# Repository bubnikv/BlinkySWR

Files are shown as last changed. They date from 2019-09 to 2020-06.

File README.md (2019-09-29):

# BlinkySWR

Tiny, cheap, simple, accurate, self powered resistive SWR and power meter for SOTA and back packers

The SWR and power meter is based on a resistive bridge. The forward and reflected power is sampled by an ATTiny13A micro controller. The micro controller is powered by rectifying a tiny fraction of the input power, and the measured SWR and power is displayed by smoothly interpolating 6 high efficiency LED diodes.

Firmware for the ATTiny13A is found [here](firmware), while the simulation and design data is found [here](design).

The following picture shows the initial prototype of BlinkySWR, indicating SWR slightly above 1:1.
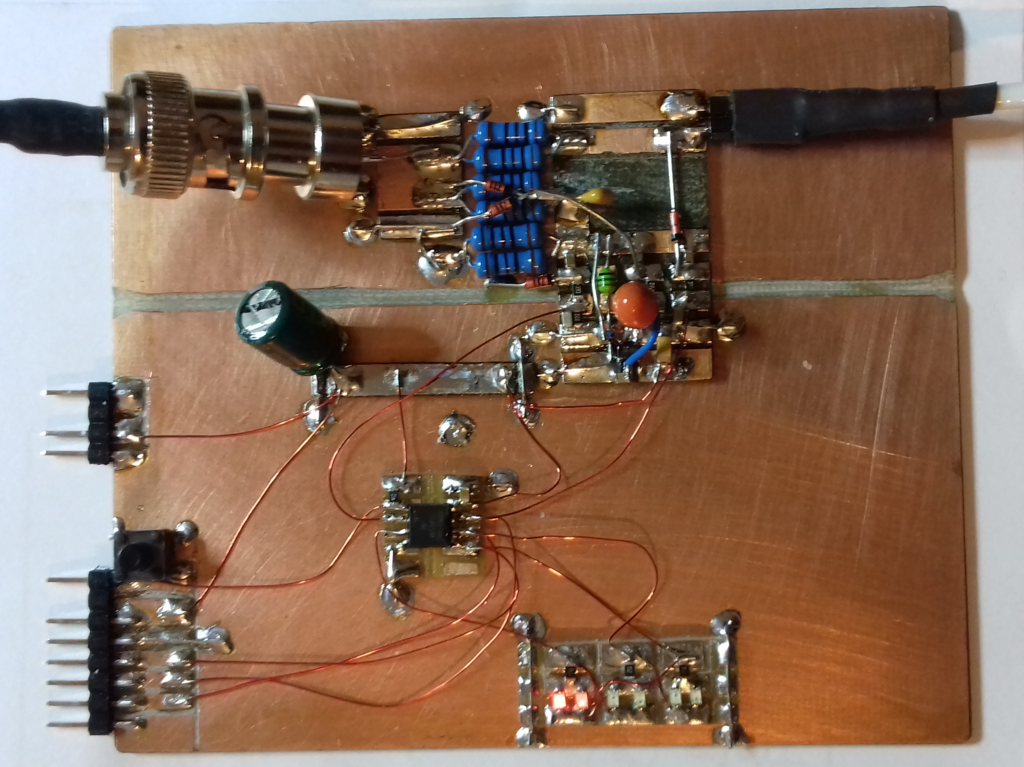
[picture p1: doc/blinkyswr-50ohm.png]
BlinkySWR prototype


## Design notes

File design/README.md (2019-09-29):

# Simulation and design

The BlinkySWR DC power recovery and SWR sampling circuits were simulated using the excellent free, unfortunately not open source [LTSpice](https://www.analog.com/en/design-center/design-tools-and-calculators/ltspice-simulator.html) tool by Linear Technologies. Installers for Windows and OSX are provided, and Linear Technologies makes sure that the Windows build runs under Wine on Linux.

The data produced by LTSpice was processed using the [Octave](https://www.gnu.org/software/octave/) software package, which is a free and open source alternative to [Matlab](https://www.mathworks.com/products/matlab.html) by [MathWorks](https://www.mathworks.com).

### Sampling circuit correction

The forward and reverse power is sampled by a hot carrier Shottky diode 1N5711, and the voltage drop at the sampling diode follows roughly the [Shockley diode equation](https://en.wikipedia.org/wiki/Shockley_diode_equation). We take an approach of modelling the sampling circuit in LTSpice using the SPICE model of the 1N5711 provided by [Diodes Incorporated](https://www.diodes.com/design/tools/spice-models/), providing a richer description of the diode behaviour than the [Shockley diode equation](https://en.wikipedia.org/wiki/Shockley_diode_equation) parameters. The SPICE model of the 1N5711 diode represents typical behavior of the diode at a room temperature, therefore the power and SWR reading by the BlinkySWR will not be quite accurate at freezing temperatures or under the desert sky. Temperature calibration is possible by putting another diode into a feedback loop of an op amp as in the [Accuprobe](http://www.kk5na.com/kk5na_files/AccupManual.htm) by the superb QRP designer Joe Everhart N2CX (SK), or by measuring a voltage drop at a reference diode by the microcontroller, but the ATTiny13A has no free input available and we did not want to complicate the design with an op amp.

[ltspice/blinky-diode-curve-parametric.asc](ltspice/blinky-diode-curve-parametric.asc) is an LTSpice model of input power sampling circuit including the ATTiny13A A/D sampling circuit, parametrized with SPICE STEP command to produce simulations for with the SWR bridge open (SWR infinity, transceiver sees SWR 1:2 and it produces maximum peak voltage). The .raw file produced by LTSpice contains transient analysis curves for input peak voltages from 0 to 50V peak. The .raw file is processed by [matlab/blinky-diode-curve.m](matlab/blinky-diode-curve.m) script to produce [matlab/blinky-diode-curve.mat](matlab/blinky-diode-curve.mat) sampling diode correction curve.

The following image shows the simulated diode correction curve. The voltage at the X axis represents the A/D reading, while the Y axis represents the diode voltage drop, which needs to be added to the A/D reading to get the sampled voltage. Blue curve represents the correction curve at room temperature for a typical 1N5711 diode, while the red line represents a linear interpolation of the curve. It is clear, that the diode voltage drop is far from 0.3V for the hot carrier 1N5711 diode, usually much higher (0.5V to 0.9V).

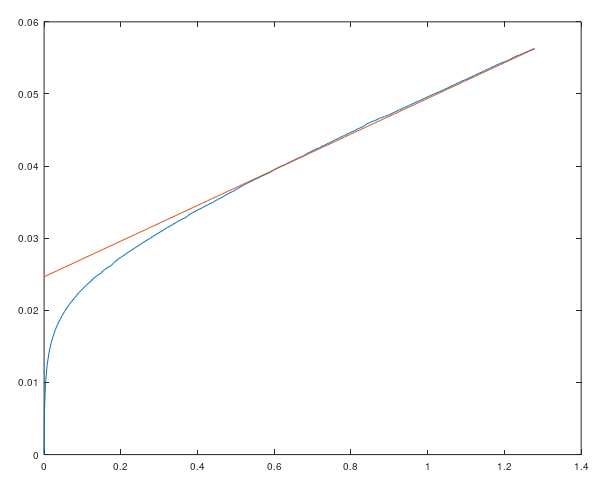
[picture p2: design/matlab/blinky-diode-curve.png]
1N5711 diode correction curve


### Other models

[ltspice/blinky-power-supply.asc](ltspice/blinky-power-supply.asc) - model of the DC power recovery, to be used for assessing currents through the diodes, loading of the transceiver and harmonics created by the loading, driven with 7MHz / 1W source.

[ltspice/blinky-diode-curve.asc](ltspice/blinky-diode-curve.asc) - model of input power sampling circuit including the ATTiny13A A/D sampling circuit, with balanced SWR bridge, driven with 7MHz / 1W source.

[ltspice/blinky-diode-curve-open.asc](ltspice/blinky-diode-curve-open.asc) - model of input power sampling circuit including the ATTiny13A A/D sampling circuit, with the SWR bridge open (SWR infinity, transceiver sees SWR 1:2 and it produces maximum peak voltage), driven with 7MHz / 1W source.

### 3rd party models and scripts

[ltspice/spicemodels_schottky_diodes.txt](ltspice/spicemodels_schottky_diodes.txt) - SPICE model of 1N5711 diode, from [ltwiki.org](http://ltwiki.org/files/LTspiceIV/Vendor%20List/Diodes%20Incorporated/Spice/spicemodels_schottky_diodes.txt)

[matlab/LTspice2Matlab.m](matlab/LTspice2Matlab.m) - 
Import of ltspice .raw files (simulation results), by [Paul Wagner](https://www.mathworks.com/matlabcentral/fileexchange/23394-fast-import-of-compressed-binary-raw-files-created-with-ltspice-circuit-simulator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), extended for Octave compatibility by [Thorben Casper](https://github.com/tc88/ANTHEM/blob/master/src/LTspice2Matlab.m)

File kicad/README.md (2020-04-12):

# BlinkySWR PCB board

KiCad PCB layout
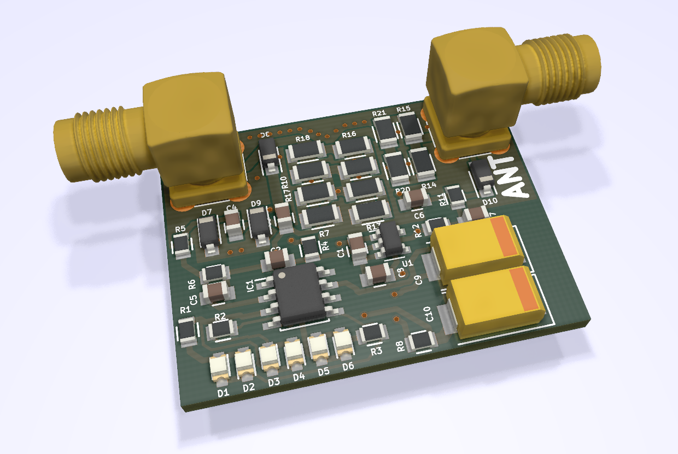
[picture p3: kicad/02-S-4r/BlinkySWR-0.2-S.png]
PCB


* [Schematics rev0.2](02-S-4r/BlinkySWR-0.2-S.pdf)
* [Interactive bom](http://htmlpreview.github.io/?https://github.com/bubnikv/BlinkySWR/blob/master/kicad/02-S-4r/ibom.html)
* [STEP 3D model](02-S-4r/BlinkySWR-0.2-S.step)

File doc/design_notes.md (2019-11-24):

# BlinkySWR design notes

The BlinkySWR is an ATtiny SWR and power meter, basically a smarter
replacement of the famous Tayloe SWR bridge. It will be a 1W to 5W (maybe a
bit higher, up to 10W) QRP resistive bridge with 6 LEDs analog-like
baragraph, with the intensity being interpolated between two successive
LEDs enhancing the baragraph resolution to at least 4x6 levels (I can
easily recognize 1 LED illuminated from 2 LEDs equally illuminated and 1
LED illuminated significantly stronger than the other). I have the
baragraph electronics and code prototyped, it works quite nicely.

The electronics (ATtiny13A driving the 6 LEDs) will be powered from a 3V
low drop low low quiescent current 16V max input linear regulator, and the
linear regulator will be powered with a 1:2 or 1:3 transformer from the
radio RF power, rectified by a single 1n5711 shottky diode (the diodes will
be used in the bridge anyway, so to reduce the BOM complexity). Look ma, no
batteries.

There will be a larger capacitor at the input side of the regulator, so the
microprocessor will have couple of seconds to perform additional tasks
after key up, that is to show the input power with quite a high accuracy.
So there will be no button: SWR will be shown during key down, and power
will be shown after a second or so after key up.

I feel quite confident with digital design and programming, but I am not
quite sure about the RF
side. Namely, what transformer should I use to feed the linear regulator?

These are my back of the envelope calculations:

On the transceiver output, when loaded with an open resistive bridge (all
three resistors 50 Ohm), the SWR is 2:1 and the voltage at the transceiver
output is 1.3333 * of Vpeak (assuming 50 Ohm output impedance of the
transceiver). Likely the maximum voltage will be lower as the output
impedance of the transceiver PA is not resistive. These are the maxima:
10W -> 42.16V Vpeak at SWR 2:1
7W -> 35.28V Vpeak at SWR 2:1
6W -> 32.65V Vpeak at SWR 2:1
5W -> 29.81V Vpeak at SWR 2:1

The minimum Vpeak at 1W transceiver output with the resistive bridge
shorted (again producing SWR 2:1 at the transceiver) will be minimum 8V
assuming the transceiver PA output is resistive. If not, the output voltage
will be closer to 10V peak.

Now the digital circuit requires a minimum 3.1V at 1.5mA DC before the
linear stabilizer, and the power will be rectified with a single diode, but
the micro will likely work happily down to 2V even if the linear regulator
just passes the voltage unregulated, as the micro may use its internal 1.1V
voltage reference for measurements. Operating the micro unregulated sounds
unusual, but it may be a viable option if tested, especially if the input
voltage will be stable enough due to the large capacitor before the
regulator.

Now my question is:
1) Should I use a 1:2 or 1:3 transformer? Using the 1:2 transformer may
require additional zener diode and likely a resistor before the linear
stabilizer if the input voltage could exceed 16V peak.
2) What will be the tiniest / cheapest ferrite and how many widings will be
optimal? I suppose this decision will be strongly dependent on the bands
supported. My personal goal is a 40m-20m EFHW tuner.

And also:

Will there be an interest for a kit?
Through hole or SMD? It may be a nice "introduction to SMD" kit as the
number of parts will be pretty low.
What bands?
What power range?
Should it contain an EFHW tuner? My personal preference would be a "NJQRP
Rainbow Tuner" like setup covering 40m-20m with a T50-6 transformer, mica
compression capacitor trimmer, jumpers to select the primary winding with
another jumper to add a capacitance for 40m coverage.

Thanks and 73,
Vojtech OK1IAK (former AB2ZA)

By kb1gmx

I pondered the idea an using a QRP radio or even a 20W radio where 
some larger chunk of power out goes to SWR/power meter tp power it
seems wrong.   Even if the suggested electronics uses a watt on a 5W 
radio that's a lot of power not going to the antenna.

Also Tayloe bridge SWR meters are a source of some 6-10db of 
insertion loss.  This is good while tuning the antenna as it 
protects the transmitter from a bad swr but unacceptable 
for inline use.   So the SWR detector (directional coupler) for inline
use should be of the Tandem match type or similar and even 
that sampler eats a little transmitter power.  The only point 
for it is now reflected power so a simple display works fine.
For power a meter will be far higher resolution.

Why not just use power from the radios  9-15V battery or an internal one? 
 Saves a lot of extra electronics and doesn't hurt the power out of the TX.
For intermittent use the battery would be small.

As to the EFHW antenna matching unit make it outboard in case 
you use a different antenna.  For 40-202m a T50-2 or T68-2 should 
do the job there are lots of schemes on the net for doing this.

Allison

Vojtech Bubnik
Even if the suggested electronics uses a watt on a 5W radio that's a lot of power not going to the antenna.
The suggested SWR meter shall draw roughly 1.5mA using a 1:2 or 1:3 transformer from the transceiver. Using a 1:2 transformer, with the assumption that only the positive polarity peak will be rectified, to source a 1.5mA voltage regulator, the circuit will draw 3mA from the source at the positive voltage peaks. Transformed by the 1:2 transformer, the current requirement will be halved, that is 1.5mA. 

At 5W the maximum peak voltage at the transmitter terminals when loaded with an open resistive bridge will be 29.81V. That corresponds to a 45mW power loss mostly in the linear regulator, that is roughly 1% of the input power.
At 10W it will be 63mW.
At 1W the power drawn to source the SWR meter electronics will be 10V * 1.5mA = 15mW, that is still 1.5% of the input power, that corresponds to -18dB power lost.

The SWR bridge current requirements may likely be even a bit lower, the 1.5mA is quite a conservative estimate using lower CPU speed and highest efficiency LED diodes.

I would be thankful if you correct my thoughs if I am wrong. I am more a software engineer than an electronics engineer.

Vojtech

kb1gmx

If your running a micro 1.5ma seems very low and LEDs you can see in 
daylight want a few ma to themselves.

Also don't forget the transformer and rectifier is a load ont he transmitter and 
that is in parallel with the antenna or dummy load which contributes to
SWR .  That whole DC recovery has an impedance and what is that?
How will the transmitter behave with that addded (loss in power 
and stability with a mismatched load).

There is no something for nothing in RF if your using power from the 
transmitter you also contributing load and possible reactance to the 
transmitters total load.  Also the transformer, rectifier and power 
converter do not deliver efficiency as components have loss.

That and the spec for the MPU used may hit low power but 
soon as the IO and A/D does something that goes up.

If the power needed is so low a few coin cells would power 
it for a very long time.  A CR3020  cell is about 225mah. 
That would save messing with RF and dealing with 
inefficiencies of power conversion.  You already have a 
battery to run the transmitter why suffer the cost in 
efficiency and losses (transfomer loss, rectifier loss, 
regulator loss) to convert DC to RF and then back to 
DC.  Keep in mind that a CW rig running class E might 
be 90% efficient but if it s class C its only 70% and 
it can easily be lower. If SSB those linear amps are maybe 
55% at full power and at less than half power 25% would 
be good.  So converting precious battery to RF then back 
to DC is at best inefficient.

You are correct save for your also incomplete in your loss projections.
Transformers are not 100% efficient, same for diodes (.2V at 1.5ma is 
0.3 mw of loss per diode).  Since the diodes are switches they generate 
harmonic waveforms that will be contributed to the output of the 
transmitter.  That's harder to predict as it varies with power in and 
load power needs.  In any case it needs to sty below the requirent
but the telecommunications rehulatory (FCC, PTT, other) 
agencies as well as good engineering practice.

In the end you get pecked to death a little at a time by ducks.

I do hardware, software, as well as RF for the last 50 years.

Allison
-- 

Vojtech Bubnik
There are two reasons to try it: First, it is challenge therefore fun. Second, it shall be an external box and it is great to not to worry about flat batteries.

1 mA flowing through a clear high intensity red LED makes my eyes hurt indoors.

Since the diodes are switches they generate 
harmonic waveforms that will be contributed to the output of the 
transmitter.

I will draw the current before the resistive bridge, therefore the harmonics will be attenuated. And the harmonics will be generated during the tune procedure only. I suppose that at 1.5% power consumed by the rectifier these harmonics will be quite weak.

I think it is time to test it. If I fail, at least I will learn something. Going shopping for the linear regulators.

Vojtech

I have a prototype working, see the attached photos showing the infinite SWR with open antenna terminals by lighting up the last LED, and showing a SWR roughly 1:1.1 with a 50 Ohm load. The bridge is powered with around 1.5W input power at 40m.

The six orange LEDs are interpolated by PWM, showing smooth transitions between levels. The SWR scale is following:
1st LED - 1:1
2nd LED - 1:1.5
3rd LED - 1:2
4th LED - 1:3
5th LED - 1:5
6th LED - 1:8 and higher

therefore the 1st LED being illuminated significantly more than the 2nd LED indicates SWR somwhere between 1:1 and 1:125.

On key up, the SWR meter is powered from a large 1000uF capacitor for around 1 second to blink the power detected on the 6 LED scale. I think that is all the functionality I can manage to squeeze into the 1kB of FLASH of this tiny $1 micro.

The device works somehow, but it is far from optimal. The micro is powered by a full wave rectifier with an artificial ground in the middle of the resistive bridge. As long as the current drawn is low, such arrangement should not cause significant read out errors or harmonics generated. I plan to do simulations of harmonic content in ltspice. The SWR bridge electronics is grounded to the virtual ground with a low impedance wire, therefore it shall be physically as tiny as possible to produce as little as possible capacitance against the other poles of the bridge, and this capacitance shall be balanced. The other three connections from the electronics to the SWR bridge are high impedance (1kOhm for power, 39kOhm for the forward and reflected power read outs).
 I do not consider myself an expert in RF electronics, though I have a feeling that such a setup will be less than optimal above 20m due to the low impedance path between the electronics ground and the virtual ground at the bridge, but with today's tiny SMD circuitry the capacity may be lower than expected.

There is a lot of work to be done on fine tuning the firmware and possibly the circuit. The firmware should utilize power saving features of the micro to a full extent, it should run the A/D conversion with all the processing disabled to lower the noise, it should use averaging to improve read out SNR, the diode detector read out shall be linearised. Currently the electronics draws around 2.5mA from the transceiver with 1mA flowing through the LEDs. To lower the micro current below the planned 1.5mA, as low as possible Vcc shall be used, likely around 2.2 to 2.5V. The micro would work from 1.8V, but a little bit higher voltag is required to have enough of current regulation on the resistors powering the low voltage red LEDs. The CPU shall be operated at as low as possible CPU frequency.

It is an interesting engineering optimization task, it is a lot of fun, and it is manageable due to the simplicity of the circuit and the ATtiny13A micro. As always, I will be thankful for constructive criticism of my endeavors.

----------------------

I ran some simulation of the power recovery circuit in ltspice. With the assumption, that the controller driving the LED baragraph draws 1.2mA at 2.4V, the following peak currents of the power recovery diodes were simulated, and the following harmonic distortion values were simulated as well. Only 3rd harmonic levels below the carrier are shown as they are most pronounced. Long story short, the worst harmonic simulation was 3rd harmonic at -34dB below the carrier. I would say this is a pretty harmless value for a circuit, that is inserted between the transceiver and antenna only during antenna adjustment.

1.2mA at 2.4V is a realistic value if all the AtTiny13A power saving features are used and LED current is limited to 1mA.

At 1W input power:
At SWR 1:1, the diode peak current is 7.4mA, which is 3.7% of 200mA input peak current, and 3rd harmonic introduced by the power recovery circuit is -36dB below the carrier.
When antenna open, the diode peak current is 8,3mA, which is 6.1% of 135mA input peak current, and 3rd harmonic introduced by the power recovery circuit is -34dB below the carrier. This is the worst distortion value.
When antenna shorted, the diode peak current is 7mA, which is 2.9% of 240mA input peak current, and 3rd harmonic introduced by the power recovery circuit is -39dB below the carrier.

At 10W input power:
At SWR 1:1, the diode peak current is 11.5mA, which is 1.8% of 636mA input peak current, and 3rd harmonic introduced by the power recovery circuit is -36dB below the carrier.
When antenna open, the diode peak current is 13mA, which is 3% of 427mA input peak current, and 3rd harmonic introduced by the power recovery circuit is -35dB below the carrier.
When antenna shorted, the diode peak current is 11mA, which is 1.4% of 764mA input peak current, and 3rd harmonic introduced by the power recovery circuit is -36dB below the carrier.

-----------------------------

* Zdokumentovat spotřebu při max SWR (svítí jedna LED): 940 mA
* Zdokumentovat proud přez tu poslední LED: 1.17V na 1.5kOhm = 0.78mA -> 160mA na procesoru
* Znovu ověřit převodní tabulku.
* Ověřit simulaci SWR trimrem pro různé úrovně vstupního výkonu.
* Naladit svítivost méně nasvětlené LEDky z páru. Moc málo?
Programovátko + naprogramovat nějaký kusy? (krajní piny na jedné straně, všechy piny na druhé).

Zdokumentovat UI a omezení:
* nefunguje na SSB, potřebuje steady signál, nefunguje na CW tečky a čárky (ověř): Funguje na pomalejší CW, ale při key off glitches
* pro měření výkonu filtruje poslední 3 samply, spočítej spoždění, jak pozvolné může být CW shaping. (4 poslední samply nad 0.2W), 3x14ms=40ms.

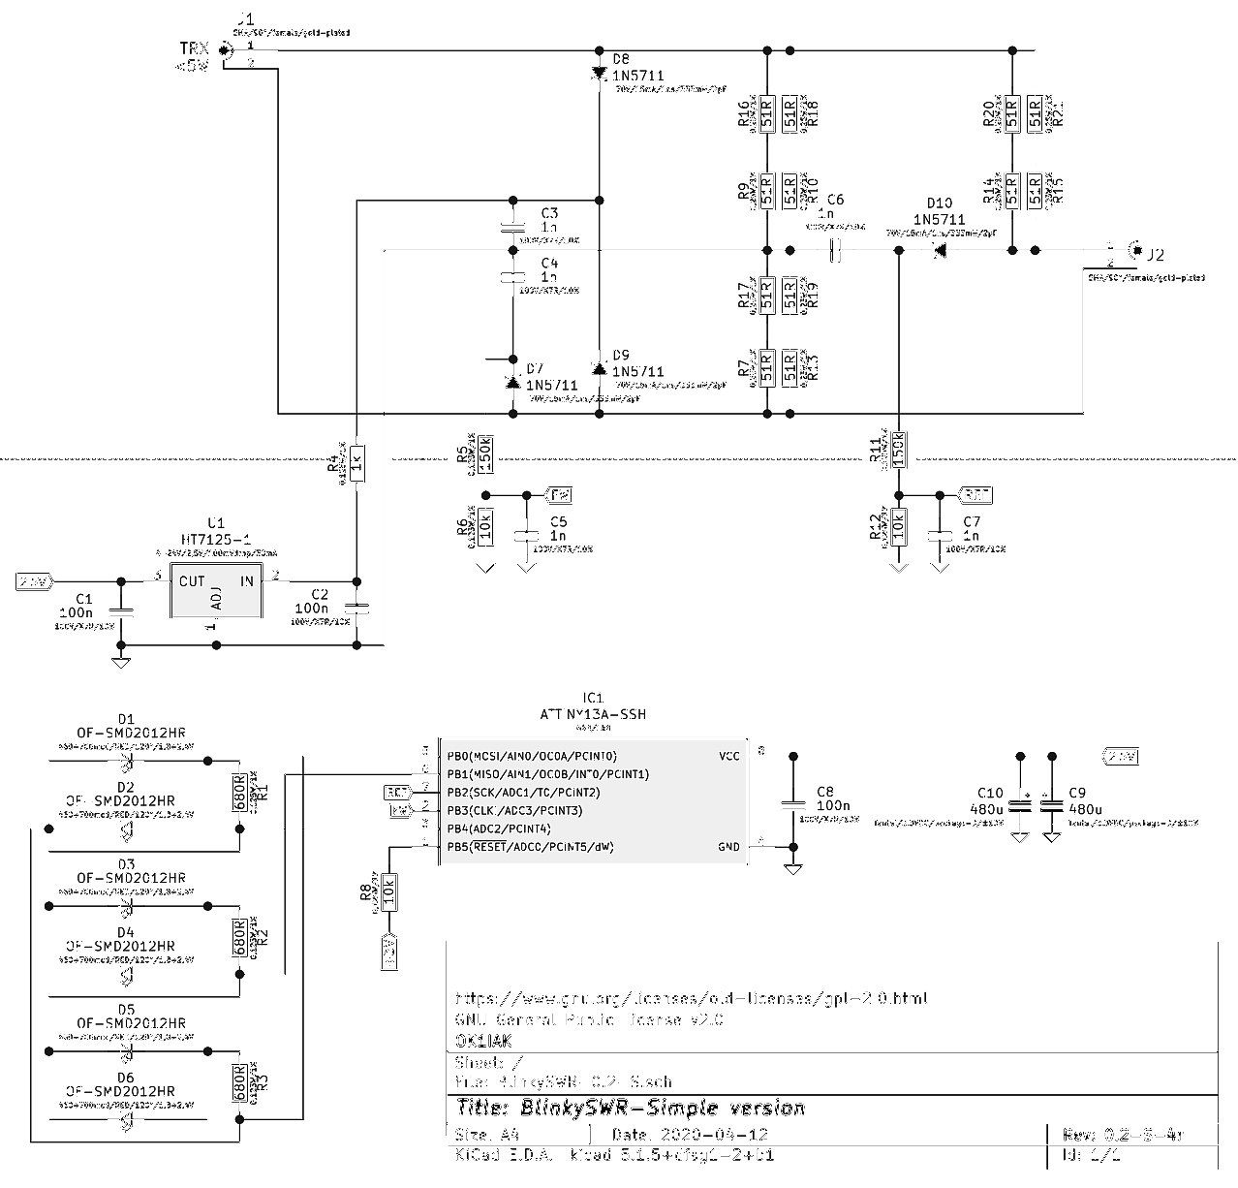
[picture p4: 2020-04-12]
doc/blinkyswr-schematic-0.2-S.png

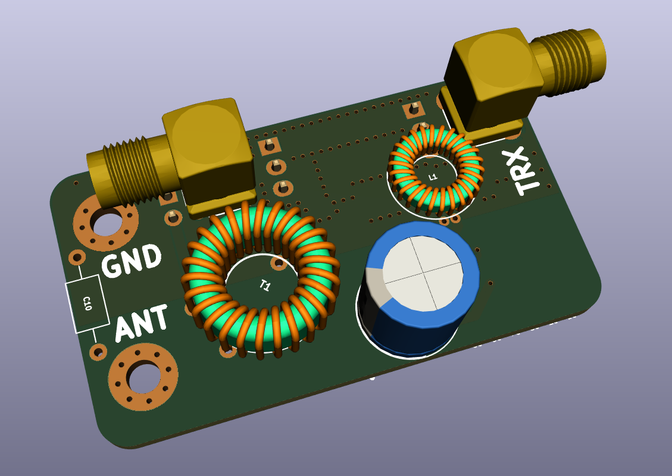
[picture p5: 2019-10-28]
kicad/01/BlinkySWR-b.png

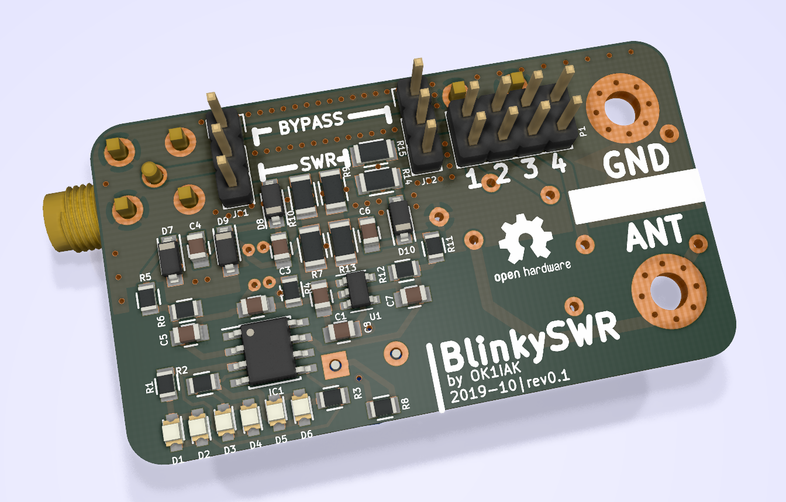
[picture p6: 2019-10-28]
kicad/01/BlinkySWR-f.png

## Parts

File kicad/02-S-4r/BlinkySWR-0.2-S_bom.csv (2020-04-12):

Comment | Designator | Footprint | LCSC | LCSC | req
1n | C6,C7,C4,C3,C5 | Capacitors_SMD:C_0805 |  | C15177 | 100V/X7R/10%
100n | C8,C1,C2 | Capacitors_SMD:C_0805 |  | C28233 | 100V/X7R/10%
480u | C9,C10 | Capacitors_Tantalum_SMD:Tantalum_Case-D_EIA-7343-31_Reflow |  | C106188 | Tantal/3,3VDC/package-D/±10%
OF-SMD2012HR | D1,D3,D5,D6,D4,D2 | Diodes_SMD:D_0805 |  | C84256* | 460÷700mcd/RED/120°/1,8÷2,4V
1N5711 | D10,D7,D9,D8 | Diodes_SMD:SOD-123 |  | C154843 | 70V/15mA/1ns/333mW/2pF
ATTINY13A-SSH | IC1 | Housings_SOIC:SOIC-8_3.9x4.9mm_Pitch1.27mm |  | C40382* | 64B/1kB
SMA-15 | J1 | ok1hra:SMA-90 |  |  | SMA/90°/female/gold-plated
SMA-15* | J2 | ok1hra:SMA-90 |  |  | SMA/90°/female/gold-plated
Mounting_Hole_PAD 3.2mm* | MK1 | Mounting_Holes:MountingHole_3.2mm_M3_Pad_Via
680R | R1,R2,R3 | Resistors_SMD:R_0805 |  | C17798 | 0,125W/1%
150k | R11,R5 | Resistors_SMD:R_0805 |  | C17470 | 0,125W/1%
10k | R12,R8,R6 | Resistors_SMD:R_0805 |  | C17414 | 0,125W/1%
1k | R4 | Resistors_SMD:R_0805 |  | C17513 | 0,125W/1%
51R | R9,R10,R13,R7,R14,R15,R16,R18,R17,R19,R20,R21 | Resistors_SMD:R_1206 |  | C18019 | 0,25W/1%
HT7125-1 | U1 | TO_SOT_Packages_SMD:SOT-23-5 |  | C259579 | 4-24V/2,5V/100mVdrop/30mA

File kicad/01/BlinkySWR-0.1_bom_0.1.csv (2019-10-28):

Component | Description | Part | References | Value | Footprint | Quantity Per PCB | Datasheet | req | note
1 | Polarised capacitor | CP_Small | C9 | 1000u | CP_Radial_D10.0mm_P5.00mm | 1 | https://www.tme.eu/cz/details/pf0j102mnn1012/elektrolyticke-kondenzatory-tht-105degc/elite/ | 6,3VDC/Ø10x12,5mm/±20%
2 | Unpolarized capacitor | C_Small | C8 | 100n | C_0805 | 1 | https://www.tme.eu/cz/details/cl21b102kcannnc/kondenzatory-mlcc-smd-0805/samsung/ | 100V/X7R/10%
3 | Unpolarized capacitor | C_Small | C1 C2 C3 C4 C5 C6 C7 | 1n | C_0805 | 7 | https://www.tme.eu/cz/details/cl21b102kcannnc/kondenzatory-mlcc-smd-0805/samsung/ | 100V/X7R/10%
4 | Variable capacitor | C_Variable | C10 | C_Variable | C_Axial_L5.1mm_D3.1mm_P10.00mm_Horizontal | 1
5 | Schottky diode, small symbol, alternativ symbol | D_Schottky_Small_ALT | D7 D8 D9 D10 | 1N5711 | SOD-123 | 4 | https://www.tme.eu/cz/details/1n5711w-7-f/diody-schottky-smd/diodes-incorporated/ | 70V/15mA/1ns/333mW/2pF
6 |  | LED_Small-Device-modular-bed-controller-01-rescue-modular-bed-controller-02-rescue-modular-bed-controller-LED-02-rescue-modular-bed-controller-LED-03.0-rescue | D1 D2 D3 D4 D5 D6 | OF-SMD2012HR | D_0805 | 6 | https://www.tme.eu/cz/details/of-smd2012hr/diody-led-smd-barevne/optoflash/ | 460÷700mcd/RED/120°/1,8÷2,4V
7 | SO8, 1k Flash, 64B SRAM, 64B EEPROM, Debug Wire | ATTINY13A-SS | IC1 | ATTINY13A-SSH | SOIC-8_3.9x4.9mm_Pitch1.27mm | 1 | https://www.tme.eu/cz/details/attiny13a-ssh/rodina-avr-8-bitu/microchip-atmel/ | 64B/1kB
8 |  | CINCH | J1 J2 | SMA-15 | SMA-90 | 2 | https://www.tme.eu/cz/details/sma-15/konektory-sma-smb-smc/ | SMA/90°/female/gold-plated
9 | Dual Jumper, normally closed | Jumper_NC_Dual | JP1 JP2 | BYPASS | Pin_Header_Straight_1x03 | 2
10 |  | Common-mode-choke | L1 | FT37-43 | FT37-43-common-mode | 1 | https://www.rf-microwave.com/en/nbp/nmp/toroid-for-broadband-emi-filters/ft-37-43/ | 2x8 turns | http://www.toroids.info/FT37-43.php
11 | Connector, double row, 02x04 | CONN_02X04 | P1 | CONN_02X04 | Pin_Header_Straight_2x04 | 1
12 | Resistor | R | R7 R9 R10 R13 R14 R15 | 100R | R_1206 | 6 | https://www.tme.eu/cz/details/hp06-100r1%25/rezistory-smd-1206/royal-ohm/hp06w2f1000t5e/ | 0,5W/1%
13 | Resistor | R | R8 | 10k | R_0805 | 1 |  | 0,125W/1%
14 | Resistor | R | R4 | 1k | R_0805 | 1 |  | 0,125W/1%
15 | Resistor | R | R6 R12 | 2k2 | R_0805 | 2 |  | 0,125W/1%
16 | Resistor | R | R5 R11 | 39k | R_0805 | 2 |  | 0,125W/1%
17 | Resistor | R | R1 R2 R3 | 500R | R_0805 | 3 |  | 0,125W/1%
18 |  | Toroid-4in | T1 | T50-6 | T50-6-4 | 1 |  |  | http://www.toroids.info/T50-6.php
19 | 1.5A 35V Adjustable Linear Regulator, TO-3 | LM117K | U1 | HT7130-1 | SOT-23-5 | 1 | https://www.gme.cz/ht7130-1-sot23-5-holtek | 4-24V/3V/100mVdrop/30mA
Component Groups: | 19
Component Count: | 44
Fitted Components: | 44
Number of PCBs: | 1
Total components: | 44
Schematic Version: | 0.1
Schematic Date: | 2019-10-02
BoM Date: | St2.jna2019,20:39:22CEST
Schematic Source: | /home/dan/kicad/hra/iak-swr-meter/02/iak-swr-meter.sch
KiCad Version: | Eeschema 5.1.4+dfsg1-1~bpo10+1

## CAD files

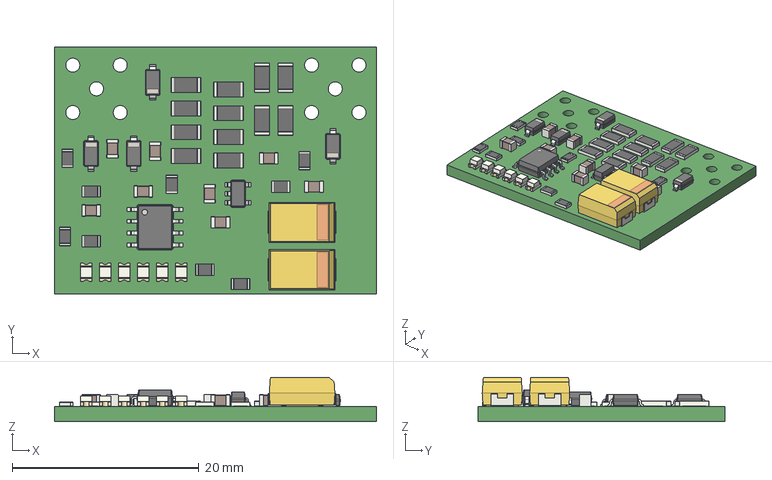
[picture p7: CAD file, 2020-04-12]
kicad/02-S-4r/BlinkySWR-0.2-S.step
34.5 x 26.5 x 4.75 mm

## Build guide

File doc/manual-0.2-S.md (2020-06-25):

# BlinkySWR

A tiny, cheap, simple, accurate, energy harvesting resistive SWR and power meter for SOTA and back packers.

Circuit and firmware by Vojtech OK1IAK, printed board design by Dan OK1HRA.

Circuit revision 0.2-S, firmware version 1.0

## Introduction

The BlinkySWR is an accurate microprocessor based replacement of the famous Tayloe SWR bridge. As such, the SWR presented by the bridge to the transceiver never exceeds 1:2. The BlinkySWR was designed with a no-tuner or limited tuning range back packing antenna installations in mind, where a Tayloe SWR bridge may not reveal the true SWR. The circuit was inspired by the [N2CX (SK) Rainbow Tuner](http://www.njqrp.club/Rainbow/rb_home.html), while being much simpler and self powered.

The SWR and power is shown by a 6 LED baragraph, where 21 discrete levels of SWR presented by interpolating intensities of neighboring LEDs, thus allowing for an analog-like SWR tuning experience. The SWR bridge electronics is powered by rectifying a tiny bit of the RF power. After transceiver key off, the measured transmit power is shortly indicated on the baragraph by discharging on board large capacitors.

The builder has to solder 6 SMD LEDs and SMD 8-pin AtTiny13A micro to the partially assembled board.

## Specification

- Maximum allowable short-term input power: 10W
- Maximum short-term power for full SWR meter resolution: 7W
- Minimum input power to power the electronics: 0.5W
- Current drawn from the transceiver to power the circuit: 1.2mA
- High SWR and power accuracy achieved by averaging eight 10bit samples and software linearization of the diode curve (power accuracy limited by the AtTiny13A internal voltage referenece).
- Continuous transmit power or slow CW (dashes) is required for the electronics to work correctly.

The SWR and power levels are shown on a 6 LED baragraph, where 4 levels are interpolated between two LED positions. 
1. LED1 fully on, LED2 fully off
2. LED1 nearly fully on, LED2 glowing a bit
3. LED1 and LED2 glowing at the same mid intensity
2. LED1 glowing a bit, LED2 nearly fully on

SWR is shown while the key is being held down. On key up, the measured power is shown at three scales: Normal, Low and High. The normal scale is shown imediately, while the low / high scale is indicated by a up / down "running light" effect preceding the power baragraph display. The baragraph SWR / power table follows:

| Baragraph | SWR | Normal Power | Low Power | High Power |
|---|---:|---:|---:|---:|
| **LED1**  |**1:1.000**| **1.00W** | **0.2500W** | |
| |  1:1.125  | 1.25W | 0.3125W | |
| 1+2 |  1:1.250  | 1.50W | 0.3750W | |
| |  1:1.375  | 1.75W | 0.4375W | |
| **LED2**  |**1:1.500**| **2.00W** | **0.5000W** | |
| |  1:1.625  | 2.25W | 0.5625W | |
| 2+3 |  1:1.750  | 2.50W | 0.6250W | |
| |  1:1.875  | 2.75W | 0.6875W | |
| **LED3**  |**1:2.00** | **3.00W** | **0.7500W** | |
| |  1:2.25 | 3.25W | 0.8125W | 6.5W |
| 3+4 |  1:2.50 | 3.50W | 0.8750W | 7.0W |
| |  1:2.75 | 3.75W | 0.9375W | 7.5W |
| **LED4**  |**1:3.00** | **4.00W** | | **8.0W** |
| |  1:3.50 | 4.25W | | 8.5W |
| 4+5 |  1:4.00 | 4.50W | | 9.0W |
| |  1:4.50 | 4.75W | | 9.5W |
| **LED5**  |**1:5.00** | **5.00W** | | **10.0W** |
| |  1:5.75 | 5.25W | | 10.5W |
| 4+5 |  1:6.50 | 5.50W | | 11.0W |
| |  1:7.25 | 5.75W | | 11.5W |
| **LED6**  |**1:8.00** | **6.00W** | | **12.0W** |

## Building the kit

#### 1) Solder the AtTiny13A.
The SOIC-8 part is quite easy to solder with a thin tipped temperature regulated soldering iron. Inspect for solder bridge with a strong light and magnifier glass or with a digital volt meter measuring resistance. Solder bridges are easily removed with a solder wick soaked in soldering flux. An excess flux is easily removed with a paper towel soaked in alcohol.

#### 2) Solder the 6 LEDs.
The LEDs are tiny and a bit challenging to solder, so we provided two spares. The cathodes are marked with a green dot and the anode / cathode flips with each LED, the neighboring LEDs are opposite oriented.

First deposit a tiny bit of solder onto the 6 pads closer to the controller. Then hold a LED with the tweezers and re-melt the already deposited bit of solder to tack one LED terminal to the board. Then solder the other LED terminal. You may then re-melt and possibly add yet a bit more solder to the 1st LED terminal. Repeat another five times.

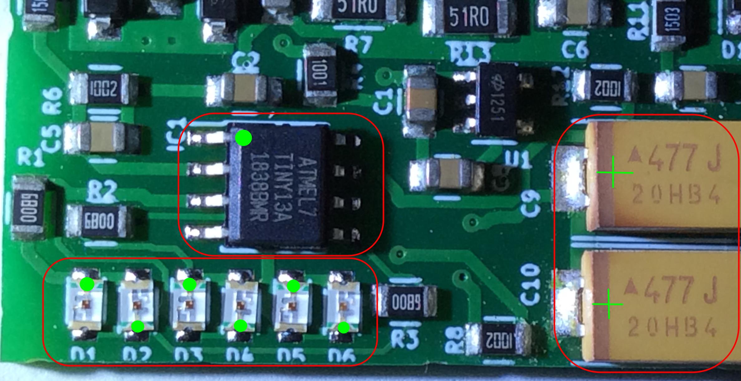
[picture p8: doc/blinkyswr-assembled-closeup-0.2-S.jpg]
BlinkySWR correctly assembled board closeup


## Application examples

The BlinkySWR could either be installed inside an antenna tuner as a replacement of the Tayloe SWR bridge, or it could be plugged between the transceiver and antenna, antenna tuner or antenna balun. The BlinkySWR uses a resistive SWR bridge, which consumes 3/4 of transceiver power, therefore the SWR bridge should be plugged out of the antenna circuit during normal transmit operation.

The BlinkySWR board is especially useful with end fed half wave tuners, which have limited or no tuning capabilities. Without an accurate SWR meter these antenna setups are often operated at improper conditions. We recommend an untuned EFHW transformer recommended by 
[Steve Dick, K1RF](http://gnarc.org/wp-content/uploads/The-End-Fed-Half-Wave-Antenna.pdf) on page 25 of his presentation. The transformer has been later analyzed by [Owen Duffy](https://owenduffy.net/blog/?p=12642). The transformer is wound with 3T:27T on a Fair-rite 2643625002 core (16.25×7.29×14.3mm, material #43), available at Mouser for a meager $0.61 in single piece quantity. We have found out, that it may be beneficial to wind the primary with 5 turns primary with taps at 3rd and 4th turn to extend the tuning range. Another good configuration is a resonant EFHW transformer wound on T50-6 iron core as in [QRP Guys tuner](https://qrpguys.com/end-fed-half-wave-sota-antenna-tuner). The resonant transformer configuration allows for some tuning and it likely  is a bit less lossy than the untuned transformer.

The BlinkySWR board fits two SMA connectors. These SMA connectors and SMA pig tails could be cheaply obtained on ebay or aliexpress. A piece of thin coaxial cable could be soldered to the BlinkySWR board directly as well.

## Design documents

For some reason github mangles the schematic. Please follow [this link to download schematic in PNG](https://raw.githubusercontent.com/bubnikv/BlinkySWR/master/doc/blinkyswr-schematic-0.2-S.png) or [this link to download schematic in PDF](https://rawgit.com/bubnikv/BlinkySWR/master/kicad/02-S-4r/BlinkySWR-0.2-S.pdf).

A complete kicad design could be [downloaded from here](https://remoteqth.com/download-count.php?Down=hw/BlinkySWR-0.2-S-4r.zip), and an interactive board view with BOM [is available here](https://rawgit.com/bubnikv/BlinkySWR/master/kicad/02-S-4r/ibom.html).

## Theory of operation

### Circuit

The BlinkySWR implements a classic resistive SWR bridge with a little twist.  Usually the bridge peak voltages are sampled against the transceiver / antenna ground level, while the BlinkySWR creates an artificial ground at half the transceiver / ground voltage level. The BlinkySWR circuit is powered by harvesting roughly 1.2mA from the transceiver and the artificial ground allows for full wave rectification of the transceiver output, therefore lowering distortion of the transceiver sine waveform caused by the energy harvesting circuit. Simulation of the energy harvesting circuit produced 3rd harmonic between -34dB and -39dB below the carrier.

The double rectified RF current is fed into a high voltage tollerant 2.5V linear regulator HT7125-1 by Holtek. This linear regulator has an extremely low quiescent current, while tollerating maximum 24V at input. This part is crucial for achieving large input power operating range.

The linear regulator is powered through a 1 kOhm resistor to limit the inrush current when charging two 470 uF electrolytic capacitors at its output. When fully discharged, the capacitors act as short circuit, therefore the 1 kOhm resistor limits the harmonics generated by the energy harvesting diodes before these capacitor charge.

The resistive SWR bridge is sampled with two 1n5711 Shottky diodes and the sampled voltage is fed into 10bit A/D converter inputs of the AtTiny13A microcontroller. Three output pins of the micro are [charlieplexed](https://en.wikipedia.org/wiki/Charlieplexing) to power one of 6 LEDs. Very high intensity red LEDs are used, as red LEDs work at 1.8V thus allowing the BlinkySWR to work at 0.5W input power, and low current is required to produce least distortion of the input waveform.

### Firmware

The AtTiny13A microcontroller was selected as a time proven, low power and cheap soltion with open C/C++ tool chain. The AtTiny13A is a low end chip with 1KB program FLASH, 64B RAM, 64B EEPROM, 5 GPIO pins and 10bit A/D converter and it was quite a challenge to squeeze all the functionality and accuracy into 1KB of program.

A prototype firmware running at high CPU speed and without utilizing the power saving functonality of the chip drew easily 1.5mA, which is about 1.5x more than the LED baragraph. The final firmware sleeps when sampling the analog inputs and between measurement cycles to lower measurement noise and power consumption. The final microprocessor power consumption is around 0.2mA.

High accuracy is achieved by 8x oversampling the forward and reverse voltages, and by compensating the non-linear characteristics of the 1n5711 diode curves by software. The sampling characteristics of the diodes was simulated in the circuit using [LTSpice](https://www.analog.com/en/design-center/design-tools-and-calculators/ltspice-simulator.html). See the [BlinkysWR design notes](https://github.com/bubnikv/BlinkySWR/tree/master/design) for LTSpice and Matlab sources. The diode curve is interpolated by two tables: One dense table samples the diode knee, while the other table samples the rest of the curve. The diode correction is then linearly interpolated from the table. One of the tables is stored in FLASH, while the other is stored in EEPROM.

More than 6 levels on the 6 LED baragraph are achieved by PWM modulating neighboring LEDs. As the clock is suppressed during the A/D sampling for reduced noise, hardware PWM was not an option and the PWM is implemented in software inside the main sampling loop. See the comments in the [firmware source code](https://github.com/bubnikv/BlinkySWR/blob/master/firmware/blinkyswr.c) for details on the main loop timing.

We tried to interpolate intensity of the neighboring LEDs smoothly, but that did not work well, as the LED intensities are not exactly equal and sensitivity of a human eye is not great either, therefore it was difficult for the operator to judge the interpolated value from the two LED intensities. At the end we decided to add just two another interpoated values: neighboring LEDs lit with equal intensities, and one LED just glowing while the other LED lit with high intensity. These levels are easy to discern even if the LEDs are not quite the same or if they are not soldered exactly flat to the printed board.

The firmware is available on [github](https://github.com/bubnikv/BlinkySWR/tree/master/firmware). The fimrware is released under [GPL2 license](https://www.gnu.org/licenses/old-licenses/gpl-2.0.en.html). The latest [AVR GCC toolchain](https://www.microchip.com/mplab/avr-support/avr-and-arm-toolchains-c-compilers) from Microchip is recommended to compile BlinkySWR, as the firmware fills up the FLASH to the last byte and less optimizing compiler would not work.

## Copyright

The hardware (circuit, board design) is released under [CERN OHL 2](https://www.ohwr.org/project/cernohl/wikis/Documents/CERN-OHL-version-2) license.
The fimrware is released under [GPL2 license](https://www.gnu.org/licenses/old-licenses/gpl-2.0.en.html).

The circuit and firmware is fully open even for commercial use and we will be happy if the design is reproduced. If you do so, please cite OK1IAK and OK1HRA as authors of the original design.

## Further work

We are considering designing a tiny QRP SWR / power meter / EFHW antenna tuner combo. Actually our first prototypes were such designs. Depending on feedback & demand, we may consider reviving this project.

Another venue of future work would be measuring not two, but three voltages at the resistive bridge, allowing to calculate absolute value of an atenna admitance. Such firmware would not fit the AtTiny13A, but the new ATtiny212/412 are much more powerful and they are bargain.

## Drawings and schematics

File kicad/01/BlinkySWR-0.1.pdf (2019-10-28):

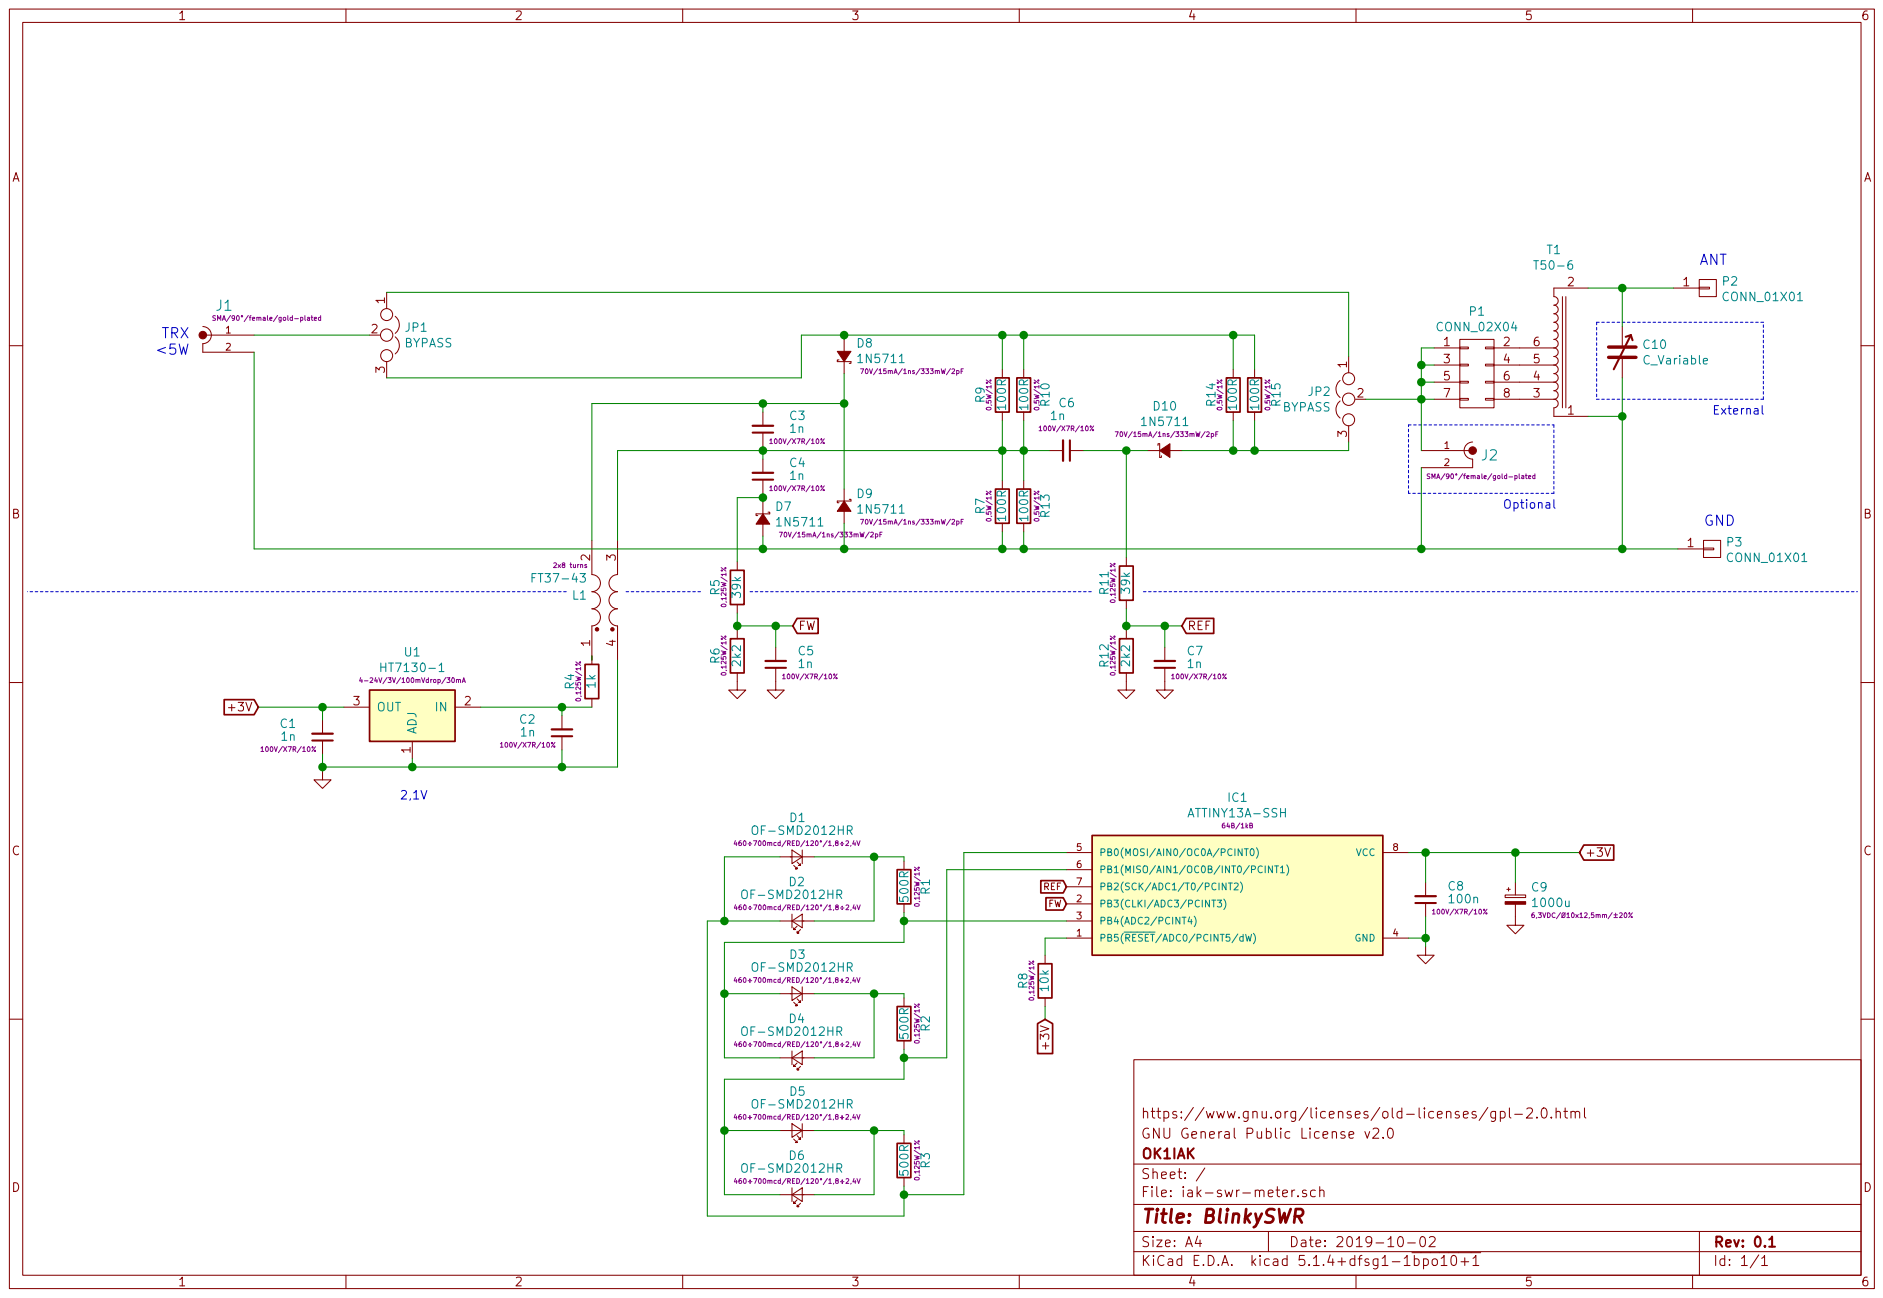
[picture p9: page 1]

3 | 4 5
5 | 6 4

SMA/90°/female/gold-plated R3 500R 0,125W/1% R2 500R 0,125W/1% R1 500R 0,125W/1% D1 OF-SMD2012HR

460÷700mcd/RED/120°/1,8÷2,4V

https://www.gnu.org/licenses/old-licenses/gpl-2.0.html D4 OF-SMD2012HR

File: iak-swr-meter.sch Sheet: / OK1IAK GNU General Public License v2.0

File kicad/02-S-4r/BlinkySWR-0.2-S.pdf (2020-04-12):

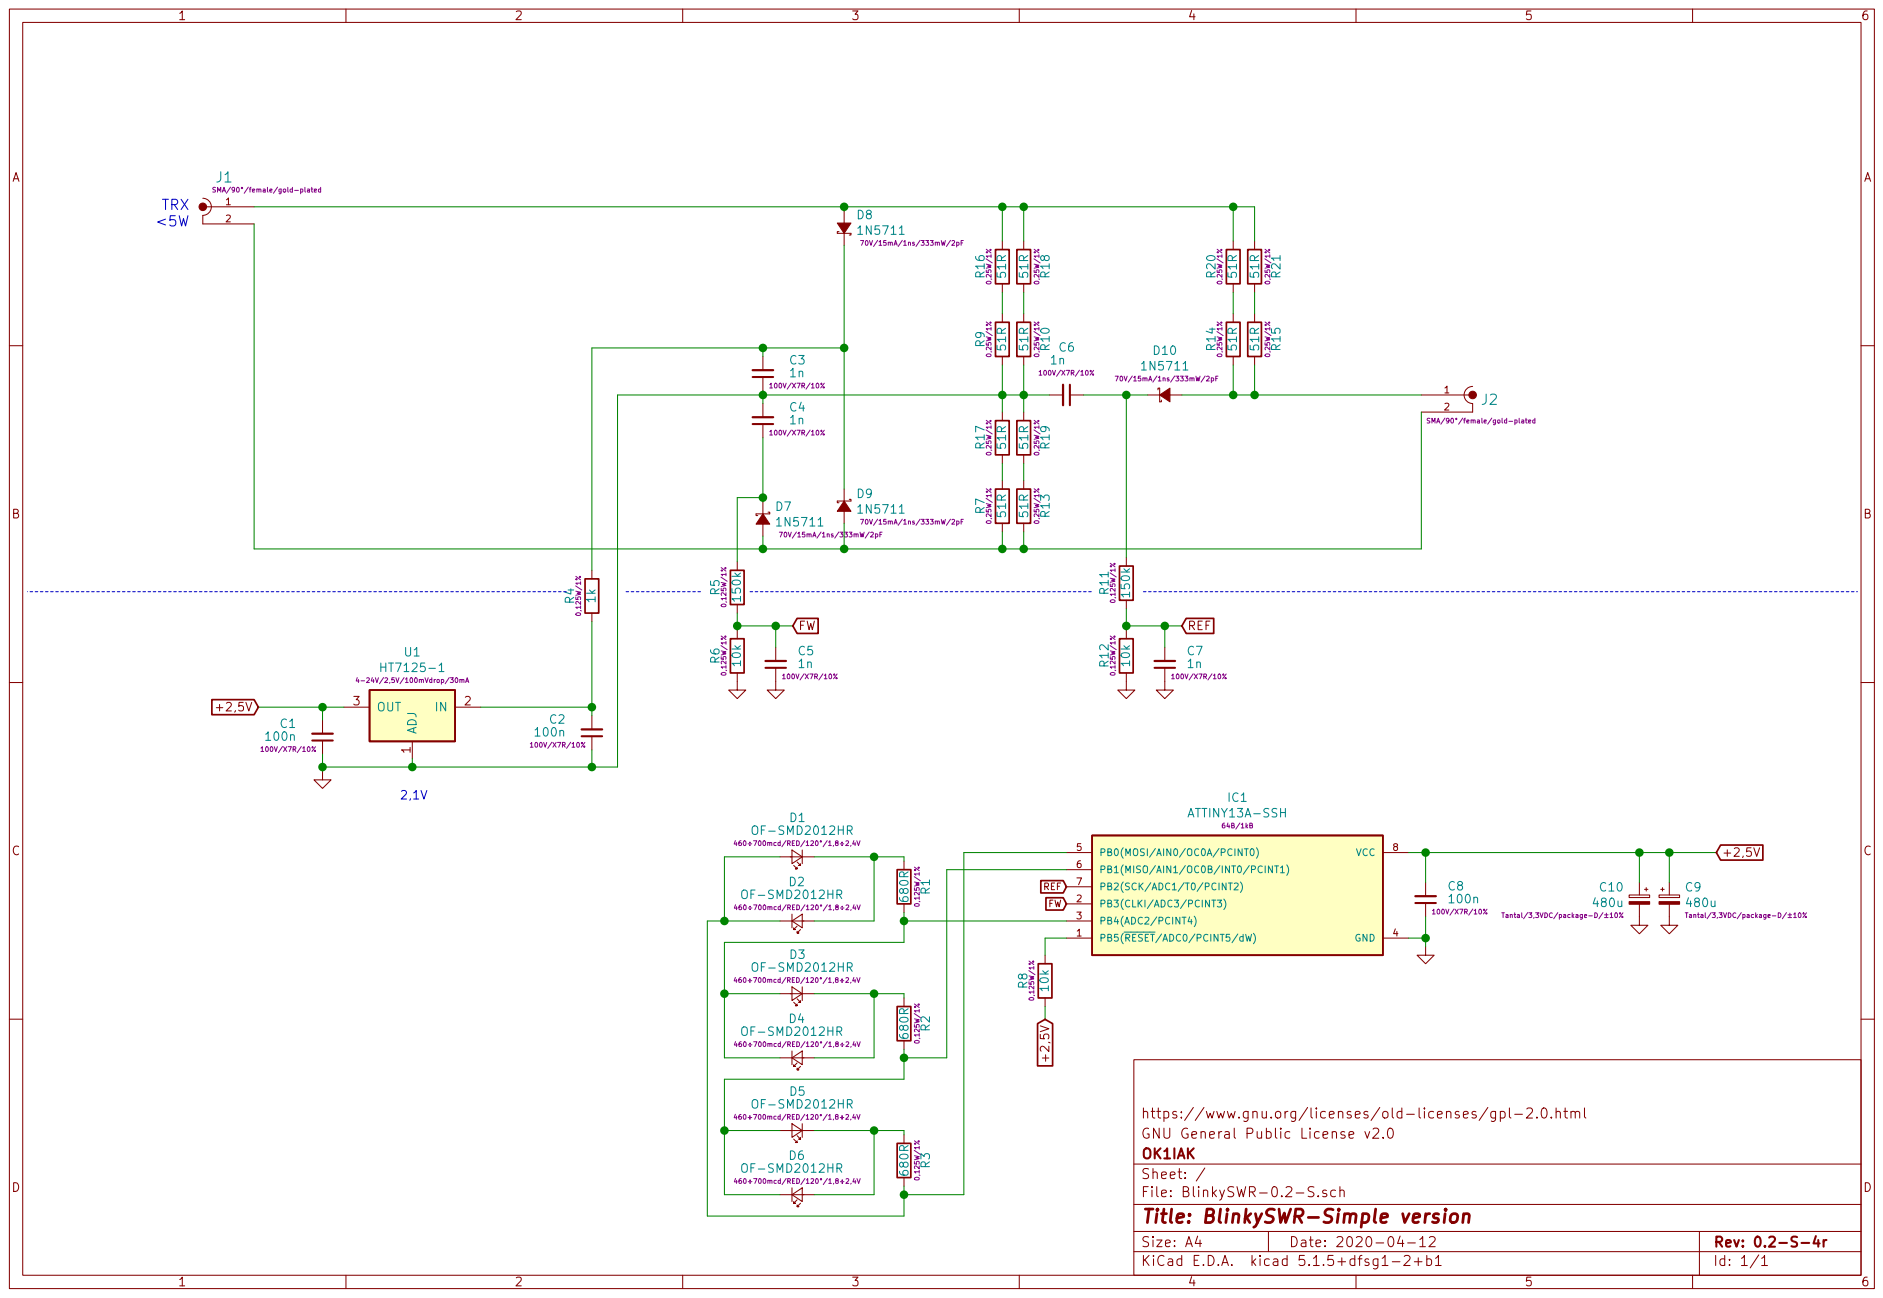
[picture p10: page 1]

File: BlinkySWR-0.2-S.sch Sheet: / OK1IAK GNU General Public License v2.0

Id: 1/1 Title: BlinkySWR-Simple version

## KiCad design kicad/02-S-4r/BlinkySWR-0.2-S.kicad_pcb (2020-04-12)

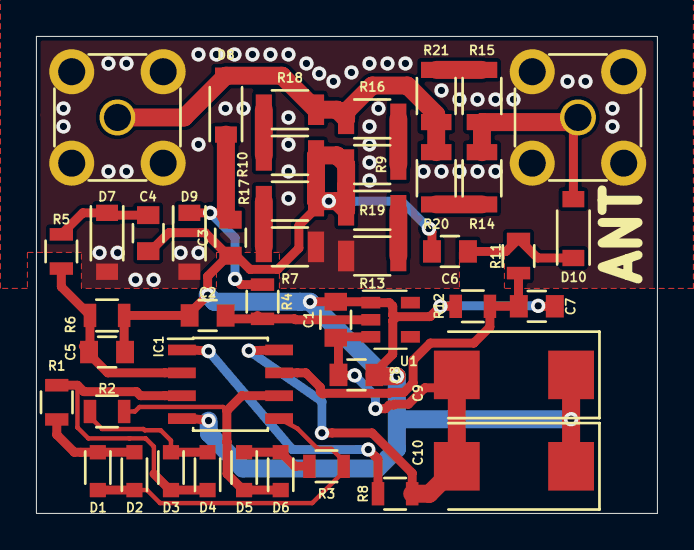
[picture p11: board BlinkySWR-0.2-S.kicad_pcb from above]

Board: 2 copper layers, 34.5 x 26.5 mm, 45 parts (0 on the bottom side), 24 nets.

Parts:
C1, C2, C8: 100n; C_0805
C3, C4, C5, C6, C7: 1n; C_0805
C9, C10: 480u; Tantalum_Case-D_EIA-7343-31_Reflow
D1, D2, D3, D4, D5, D6: OF-SMD2012HR; D_0805
D7, D8, D9, D10: 1N5711; SOD-123
IC1: ATTINY13A-SSH; SOIC-8_3.9x4.9mm_Pitch1.27mm
J1: SMA-15; SMA-90
J2: SMA-15*; SMA-90
R1, R2, R3: 680R; R_0805
R4: 1k; R_0805
R5, R11: 150k; R_0805
R6, R8, R12: 10k; R_0805
R7, R9, R10, R13, R14, R15, R16, R17, R18, R19, R20, R21: 51R; R_1206
U1: HT7125-1; SOT-23-5

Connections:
+2,5V: C1.2, C8.2, C9.1, C10.1, IC1.8, R8.2, U1.3
FW: C5.2, IC1.2, R5.2, R6.1
GND: C1.1, C2.1, C3.1, C4.2, C5.1, C6.2, C7.1, C8.1, C9.2, C10.2, IC1.4, R6.2, R9.2, R10.2, R12.2, R17.1, R19.1, U1.1
unnamed: C2.2, R4.1, U1.2
unnamed: C3.2, D8.1, D9.1, R4.2
unnamed: C4.1, D7.1, R5.1
unnamed: C6.1, D10.1, R11.1
unnamed: D1.1, D2.2, R1.2
unnamed: D1.2, D2.1, IC1.5, R3.1
unnamed: D3.1, D4.2, R2.2
unnamed: D3.2, D4.1, IC1.3, R1.1
unnamed: D5.1, D6.2, R3.2
unnamed: D5.2, D6.1, IC1.6, R2.1
unnamed: D7.2, D9.2, J1.2, J2.2, R7.2, R13.2
unnamed: D8.2, J1.1, R16.1, R18.1, R20.1, R21.1
unnamed: D10.2, J2.1, R14.2, R15.2
unnamed: IC1.1, R8.1
unnamed: R10.1, R18.2
unnamed: R13.1, R19.2
unnamed: R14.1, R20.2
unnamed: R15.1, R21.2
unnamed: R9.1, R16.2
unnamed: R7.1, R17.2
REF: C7.2, IC1.7, R11.2, R12.1

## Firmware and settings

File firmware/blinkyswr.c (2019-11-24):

// SWR / power meter powered by rectifying the transceiver output power.
// The firmware was fine tuned to draw as little current as possible, running from low VCC voltage,
// at relatively low CPU speed and sleeping as much as possible.
// The firmware fits the 1kB FLASH of the AtTiny13A tightly, and the firmware only fits if a newer GCC compiler tool chain is used.
// We have used the GCC tool chain provided by the chip vendor.

// The AtTiny13A is clocked by an internal RC oscillator running at approximately 9.6MHz. This oscillator is being calibrated at production & testing of the chips, the calibration value is written into a FLASH block not accessible to the firmware, and the calibration value is loaded at the reset.

// The CPU clock is set to 9.6 MHz / 8 = 1.2 MHz by setting the appropriate programming fuse.
// The ADC clock is set to 1.2 MHZ / 16 = 75 kHz.
// As each ADC conversion takes 13 cycles, the maximum ADC sampling rate is then 75 kHz / 13 = 5.77 kHz.

// The firmware runs a main loop, which first samples the forward & reflected voltage, then it calculates the SWR and power, and
// then it sleeps up to an and of the 75 Hz period, while the 6 LED charlieplexed baragraph is modulated at the same 
// 75 Hz repeat cycle to provide smooth interpolation of light intensity between two succeeding LEDs.
// A straightforward solution would be to use the 8 bit timer to PWM between the two neighboring LEDs at 75 Hz repeat cycle.
// However, the firmware puts the CPU to "noise reduction" sleep state during ADC conversion. During the "noise reduction"
// sleep state the 8 bit timer clock is suspended, therefore it is not so simple to use the timer for the timing
// of the baragraph PWM. Our solution is to measure the time needed for all the ADC conversion, then to restart the timer
// while setting the timer initial state to the time consumed already by the ADC conversion. As the ADC time conversion 
// is relatively lengthy, the LED configuration taking the longer time is activated first, while the other LED configuration
// is activated by the timer capture event, and the cycle is repeated at the timer overflow event.

// Sampling 2x16 samples per 75kHz period seems to fit the first half of the 75kHz period with some reserve,
// but that may be sensitive to a compiler optimizations. We rather chose a conservative approach of sampling
// just 2x6 samples, which also leads to lower current consumption, as the whole sampling & SWR processing
// seems to fit into roughly 1/3 of the 75 kHz period. The time spent by the sampling & SWR processing was verified with a logic
// analyser. As it only takes 1/3 of the 75 kHz period, there is a healthy buffer for situations, where the calculation
// takes longer due to different program paths being taken.

// Input resistive divider 10k / 150k provides the required 10k input impedance to the ADC converter (see AtTiny13A datasheet).
// At 7W input power, the peak voltage at SWR 2:1 with the resistive bridge open is maximum 35.28V peak with the assumption,
// that the transceiver output impedance is purely resistive. As the transceiver output impedance is far from resistive and the transceiver is conjugate matched to the antenna, the transceiver peak voltage at 2:1 SWR will likely be lower, allowing the SWR meter likely to work up to 10W.

// At the maximum 35.28V peak voltage at the resistive bridge input, the ADC voltage at 10k / 150k resistive divider will be
// 1.1025 V, which matches the 1.1V ADC reference voltage (the voltage will be lower for the diode drop, which will be corrected
// for in the firmware).
// If the input voltage is higher, the current flowing through the 150k resistor into the micro substrate diodes will be negligible.

#include <stdbool.h>
#include <avr/interrupt.h>
#include <avr/io.h>
#include <avr/pgmspace.h>
#include <avr/sleep.h>
#include <avr/wdt.h>

#define F_CPU 1000000UL  // 1 MHz
#include <util/delay.h>

const uint16_t diode_correction_table_rough[16] PROGMEM = {
	#include "table_fine.inc"
};

#define REF_AVCC (0<<REFS0) // reference = AVCC
#define REF_INT  (1<<REFS0) // internal reference 1.1 V 

#define LINE_A 4 //Pin 3 (PB4) on ATtiny13A
#define LINE_B 0 //Pin 5 (PB0) on ATtiny13A
#define LINE_C 1 //Pin 6 (PB1) on ATtiny13A
#define ALL_LEDS ((1<<LINE_A) | (1<<LINE_B) | (1<<LINE_C))

#define ADC_PWR (1<<MUX0 | 1<<MUX1) // Pin 2 (PB3/ADC3) on ATtiny13A
#define ADC_REF (1<<MUX0) 			// Pin 7 (PB2/ADC1) on ATtiny13A

// #define DISABLE_PULLUPS 
#ifdef DISABLE_PULLUPS
	#define PUD_VALUE 0
#else /* DISABLE_PULLUPS */
	#define PUD_VALUE (1 << PUD)
#endif /* DISABLE_PULLUPS */

// DDRB direction config for each LED (1 = output)
// PORTB output config for each LED (1 = High, 0 = Low)
const unsigned char led_table[16] PROGMEM = {
  ALL_LEDS, 					0, 				// all LEDs off
  ( 1<<LINE_A | 1<<LINE_B ), 	( 1<<LINE_B ), 	// LED 0
  ( 1<<LINE_A | 1<<LINE_B ), 	( 1<<LINE_A ), 	// LED 1
  ( 1<<LINE_A | 1<<LINE_C ), 	( 1<<LINE_A ),	// LED 2
  ( 1<<LINE_A | 1<<LINE_C ), 	( 1<<LINE_C ), 	// LED 3
  ( 1<<LINE_B | 1<<LINE_C ), 	( 1<<LINE_C ), 	// LED 4
  ( 1<<LINE_B | 1<<LINE_C ), 	( 1<<LINE_B ), 	// LED 5
  ( 1<<LINE_B | 1<<LINE_C ), 	( 1<<LINE_B ) 	// LED 5: Clamp to LED5
};

// Global data are packed into a commmon structure as recommended by Atmel, as the members of the global structure
// may be addressed effectively by using a common pointer register and fixed offsets.
struct LedState {
	// Direction of PORTB pins at the 1st part of the 75 Hz period, to be loaded at the timer overflow event.
	// Output state of PORTB pins at the 1st part of the 75 Hz period, to be loaded at the timer overflow event.
	// Two bytes are bundled into a single 16bit word, so we save some FLASH space when reading the word from FLASH
	// as the macro for reading two bytes is shorter than twice a macro for reading a single byte.
	uint16_t dir_and_out1;
	// Direction of PORTB pins at the 2nd part of the 75 Hz period.
	// Output state of PORTB pins at the 2nd part of the 75 Hz period.
	uint16_t dir_and_out2;
	// New value of timer capture A to use the dir2 / out2.
	unsigned char timer_capture;
};

// #define DEBUG_SPI
// sigrok-cli -d fx2lafw -c samplerate=500k --continuous -P spi:mosi=D5:clk=D7:cs=D6 --protocol-decoder-annotations spi=mosi-data
#ifdef DEBUG_SPI
#define SPI_MOSI	LINE_A
#define SPI_CLK 	LINE_B
#define SPI_EN		LINE_C
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

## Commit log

2019-09-29 Generated the diode correction curve
2019-09-29 Updated design document with the diode correction curve
2019-09-29 Updated the front page with the links and prototype image
2019-10-02 pcb rev0.1
    [BlinkySWR-0.1-B_Cu.gbl, BlinkySWR-0.1-B_Mask.gbs, BlinkySWR-0.1-B_SilkS.gbo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]
2019-10-28 Modified the ADC divider to 150kOhm / 10kOhm for lower detector diode loading. Extended the simulations with shorted antenna situations, added the sine wave distortion values read out from the FFT si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
2019-10-29 Reworked the diode compensation curve matlab code, Intel HEX file and C include file are generated for the diode correction
2019-10-29 Updated firmware for lower power consumption by utilizing the sleep modes wherever possible. Updated the matlab generator to produce tables scaled to 16W at 32768, so that the power baragraph calcula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
2019-11-10 Fixed a scaling issue of the diode curve correction
2019-11-12 Fixed a bug in firmware in the diode correction function (data was not pulled correctly from the EEPROM).
    Software SPI for debugging by capturing the SPI data with a logic
    analyzer.
    Debugging of the diode curve correction function to SPI and
    evaluating the data captured from firmware in Octave against the ground
    truth.
    [blinkyswr.c]
2019-11-16 Fixed some bugs, optimized for FLASH consumption
    [blinkyswr.c]
2019-11-23 Added timeout for the reading to stabilize. Added scaling of the power reading.
    [blinkyswr.c]
2019-11-23 Now the REF is sampled before FWD to avoid glitches on key up
    [blinkyswr.c]
2019-11-24 Fixed an overflow and division by zero in the SWR calculation code
    [blinkyswr.c]
2020-04-12 pcb rev0.2
    [BlinkySWR-0.2-S-B_Cu.gbl, BlinkySWR-0.2-S-B_Mask.gbs, BlinkySWR-0.2-S-B_SilkS.gbo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]
2020-04-12 updated manual with schematic
2020-06-25 Added closeup photo of the board
